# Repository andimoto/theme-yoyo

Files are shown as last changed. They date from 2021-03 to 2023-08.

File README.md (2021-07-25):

# Theme-Yoyo - a Customizable Yoyo

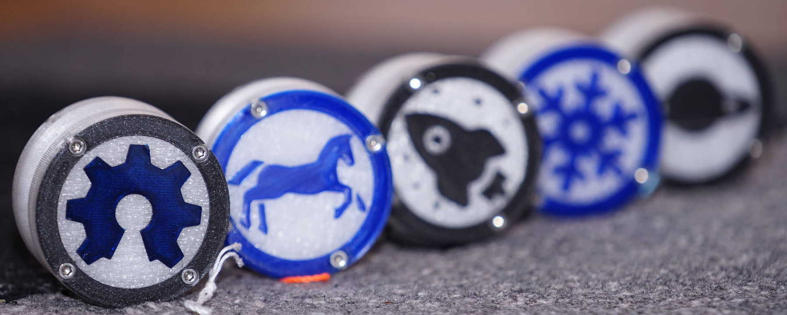
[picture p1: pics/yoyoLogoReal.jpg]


*Place your own graphics on top of the yoyo or customize it!!*

Yoyo is based of two parts, YoyoBase & ThemeBase. The YoyoBase holds both halfs together via screw and bearing (R188KK - 8-Ball-Bearing). The ThemeBase can be customized with multiple vector graphics per ThemeBase.
To add your favorite SVG motive create a 'motive configuration'. This is an array which holds the path to the file and several parameters such as 'moveXYZ', 'extrude' or 'scale'. This 'motive configuration' has to be set to the list 'motiveList'. All motives in this list will be placed on the YoyoBase. This way it is possible to place and combine multiple SVG motives.

Additionally: the 'tools'-directory contains a bash script to convert a png to svg (with pre-conversion to pnm). This script needs __'potrace'__ which can be installed via package manager (on Linux).

SVG graphics with CC0 license can be obtained at:

  - https://publicdomainvectors.org/
  - https://freesvg.org/
  - https://www.svgrepo.com

### Printing
- print ThemeBase on flat surface (graphic up)
- do color change at the graphic to separate it from background
- enable ironing on top layers the get a nice finish
- print resolution 0.1mm
- use PETG for stronger parts

#### Advices
- use filament changes to separate motive from base
- when printing multiple motives, set extrusion length (thickness) to different heights.
  This enables filament changes on different layers and get a multicolor Yoyo!

### Parts
- printed YoYo Parts (2x yoyoBase_xmm.stl, 2x YoyoThemeX.stl)
- one M3x20 screw with M3 nut for Axis
- 8 M3x6 screws (cylinder head screw)
- 2 O-Rings 15x2.5mm
- R188KK Bearing
- Cord (there are ready Yoyo Cords, relatively cheap)

### Assembling
- place the bearing onto the center of the yoyo base
- place the o-ring in both yoyo bases
- put both yoyo bases together (may be necessary to press them carefully together)
  - they should be holded together by the bearing
- screw both yoyo bases together with the M3x20 screw (do not overthight the axis)
- screw the theme parts on top of each base carefully (do not overthight them)
  - tip: measure the weigth of the theme parts and balance them out with small parts of filament
    which you can place into the furrow/gouge which are extra made for weigth balancing
- maybe the yoyo needs to be weared in some minutes

### Images
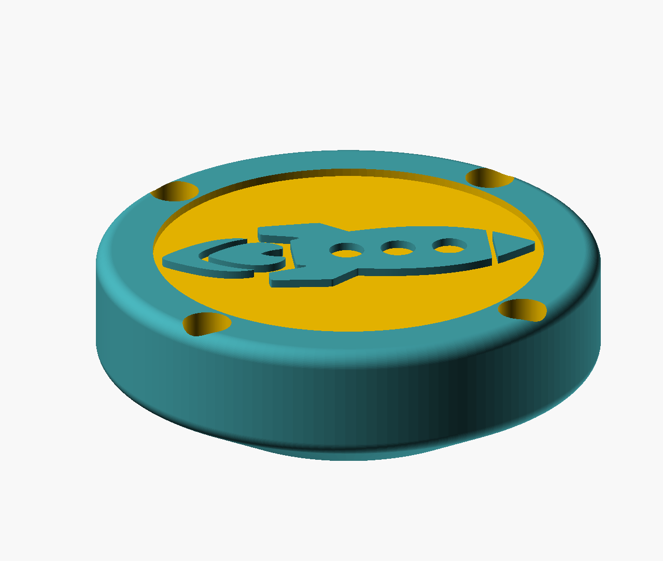
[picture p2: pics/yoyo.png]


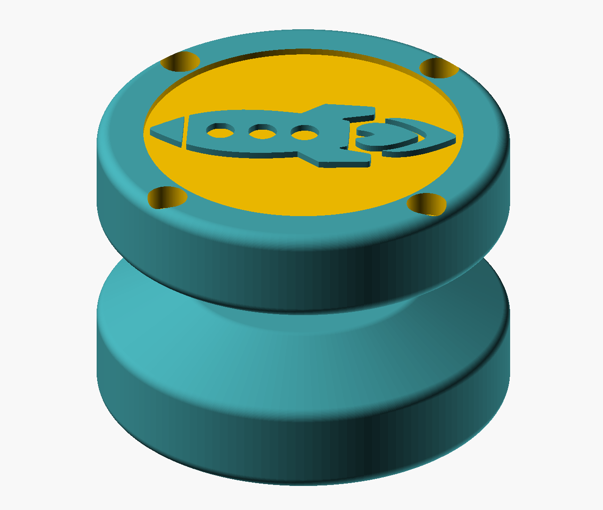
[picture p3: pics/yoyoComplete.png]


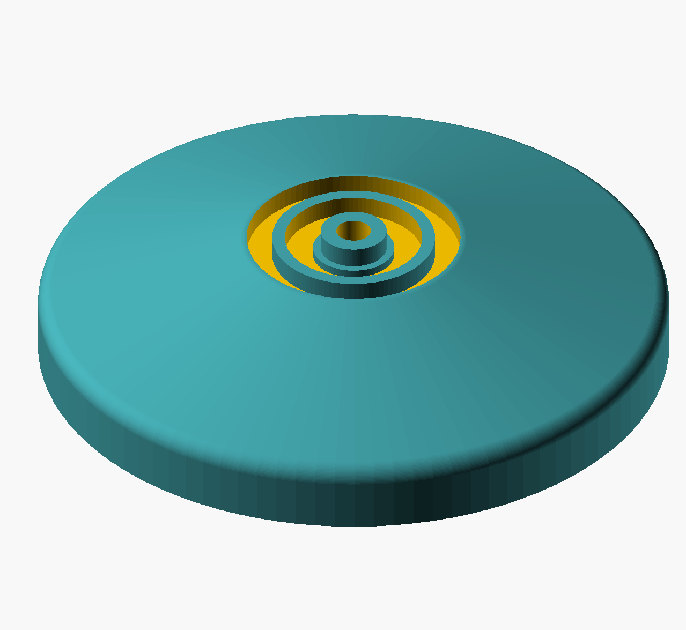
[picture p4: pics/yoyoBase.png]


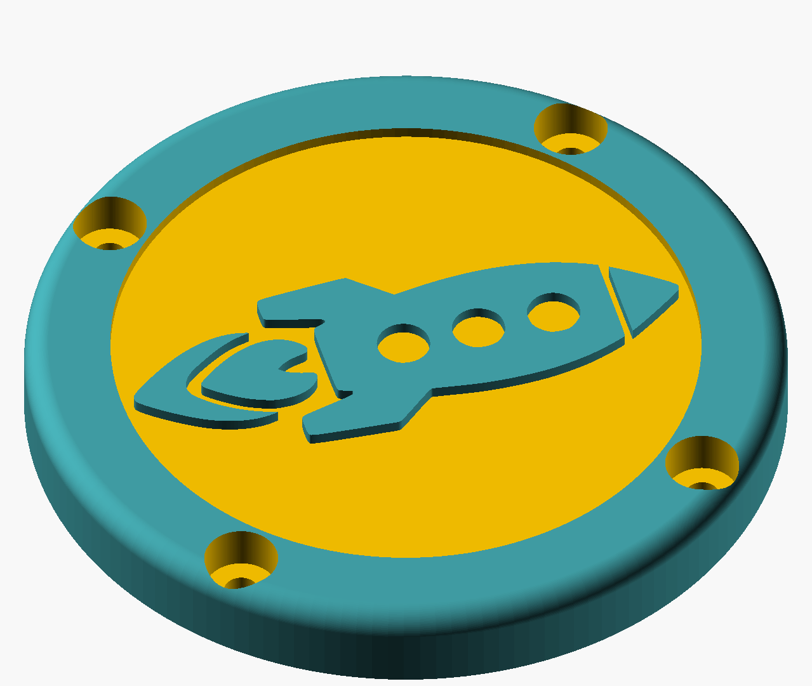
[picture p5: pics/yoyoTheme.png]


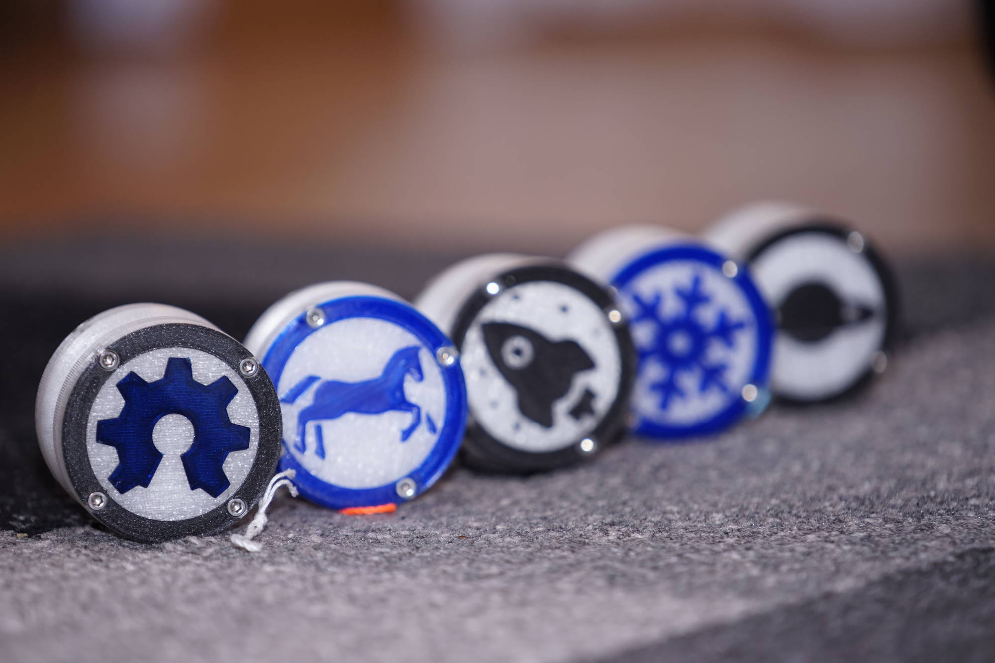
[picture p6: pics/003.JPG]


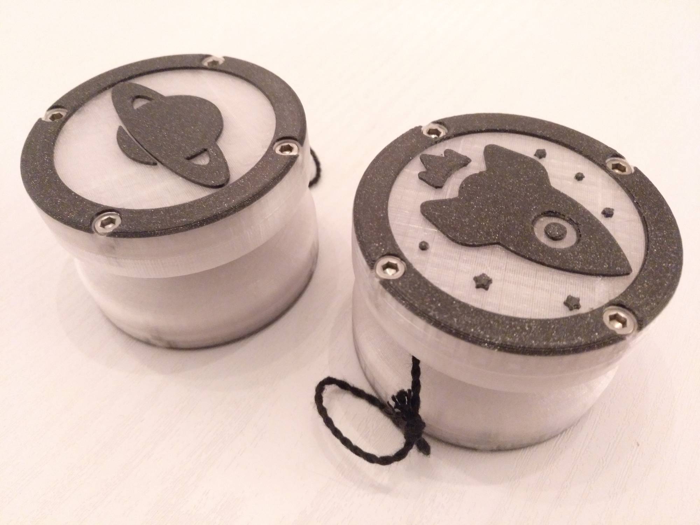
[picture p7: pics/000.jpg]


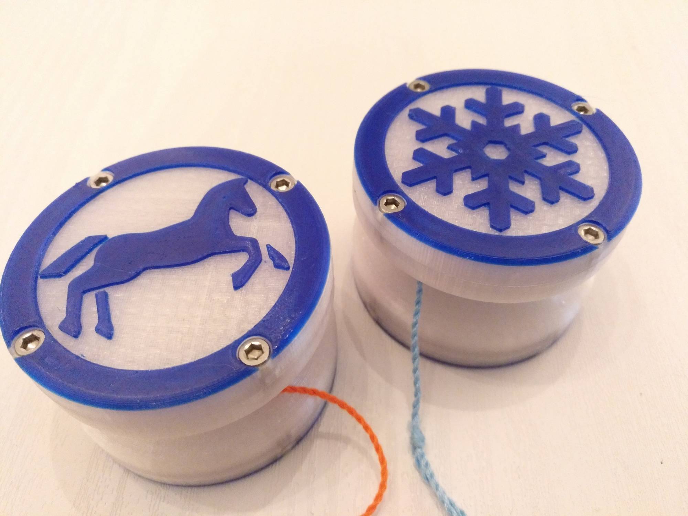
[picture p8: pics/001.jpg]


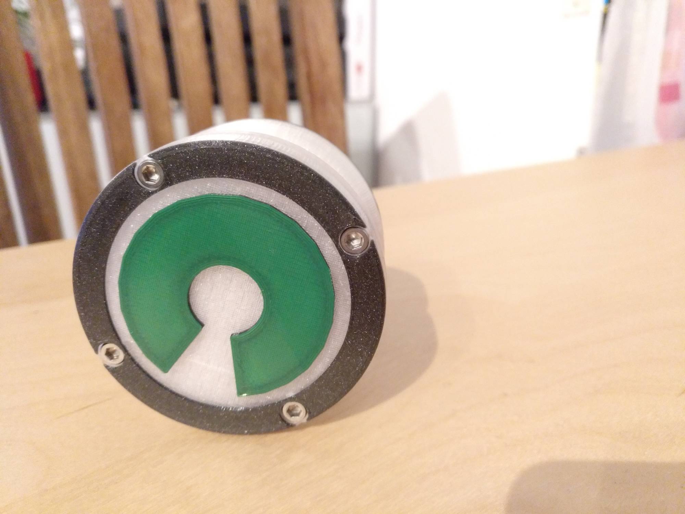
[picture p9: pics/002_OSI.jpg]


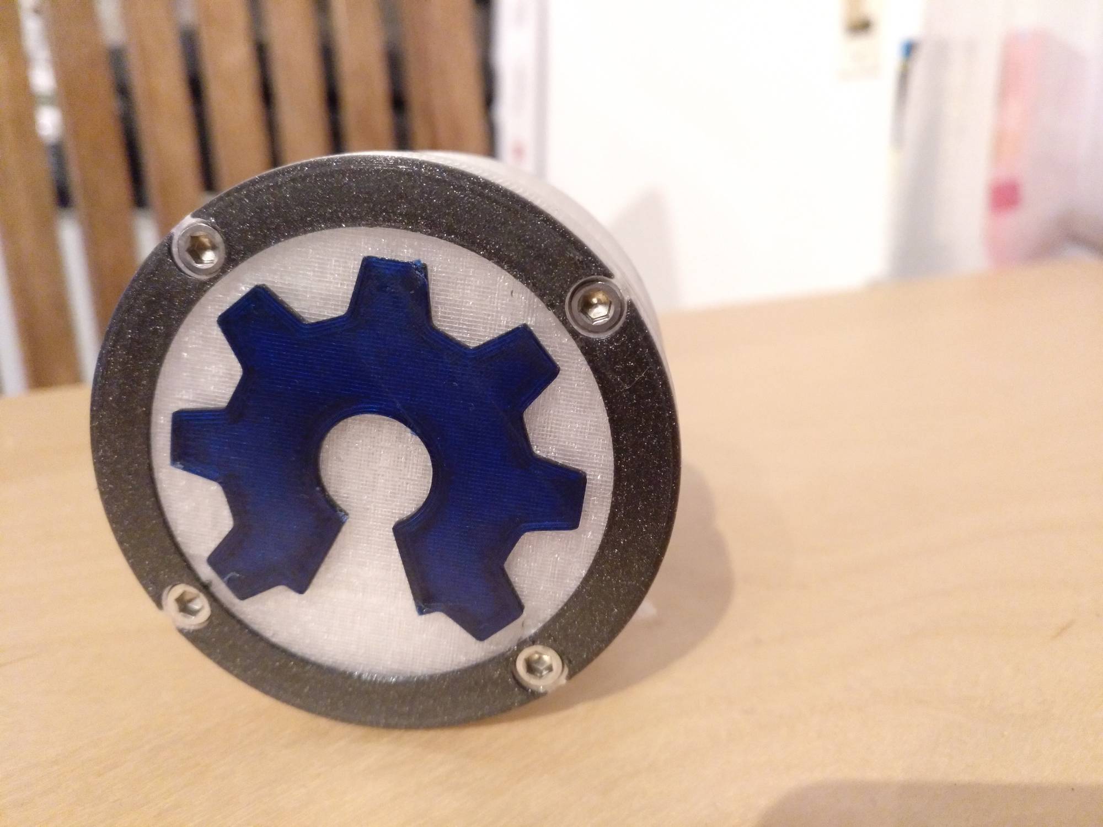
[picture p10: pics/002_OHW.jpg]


# LICENSE

<br />Dieses Werk ist lizenziert unter einer <a rel="license" href="http://creativecommons.org/licenses/by-sa/4.0/">Creative Commons Namensnennung - Weitergabe unter gleichen Bedingungen 4.0 International Lizenz</a>.

<br />This work is licensed under a <a rel="license" href="http://creativecommons.org/licenses/by-sa/4.0/">Creative Commons Attribution-ShareAlike 4.0 International License</a>.

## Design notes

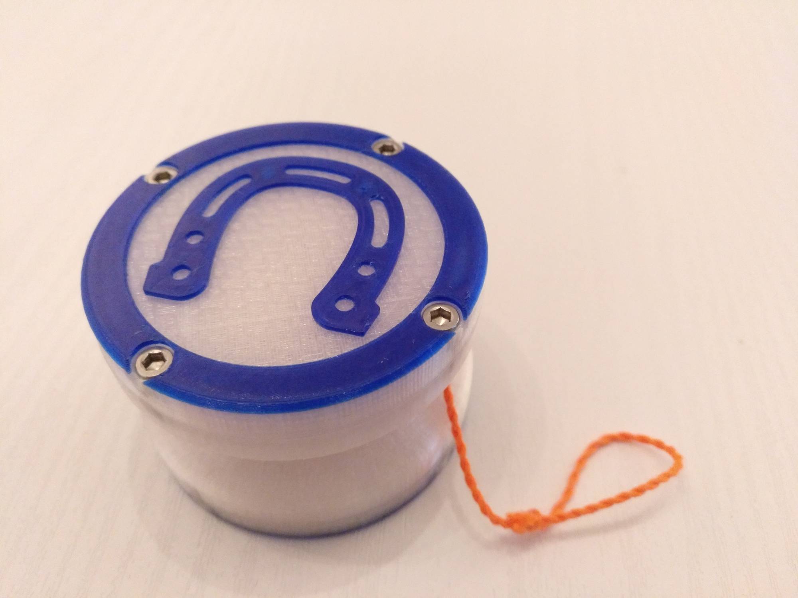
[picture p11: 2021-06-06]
pics/002_horseshoe.jpg

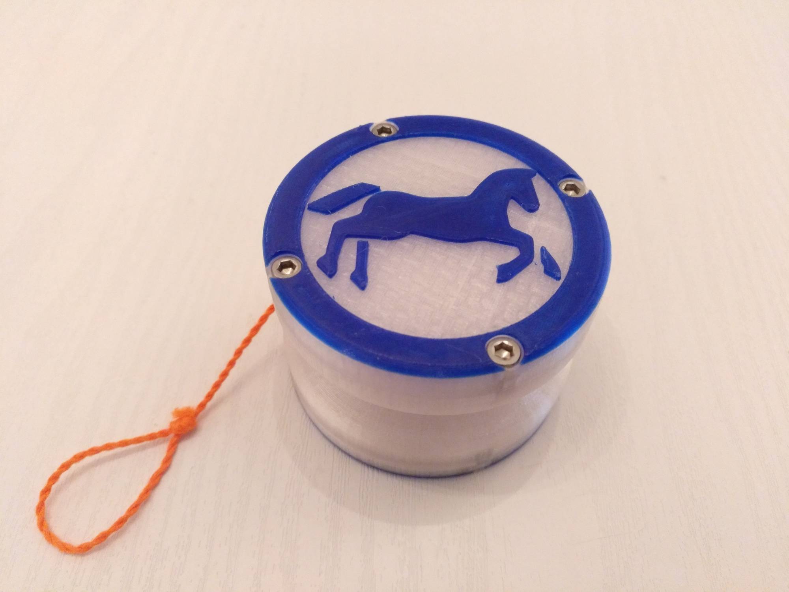
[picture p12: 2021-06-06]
pics/002_horse.jpg

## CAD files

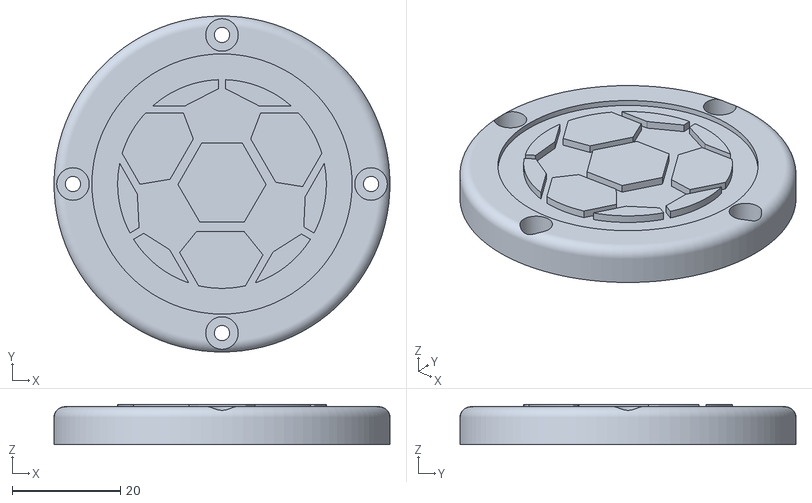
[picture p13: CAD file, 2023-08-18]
stl/yoyoThemeBall.stl
62.0 x 62.0 x 7.40

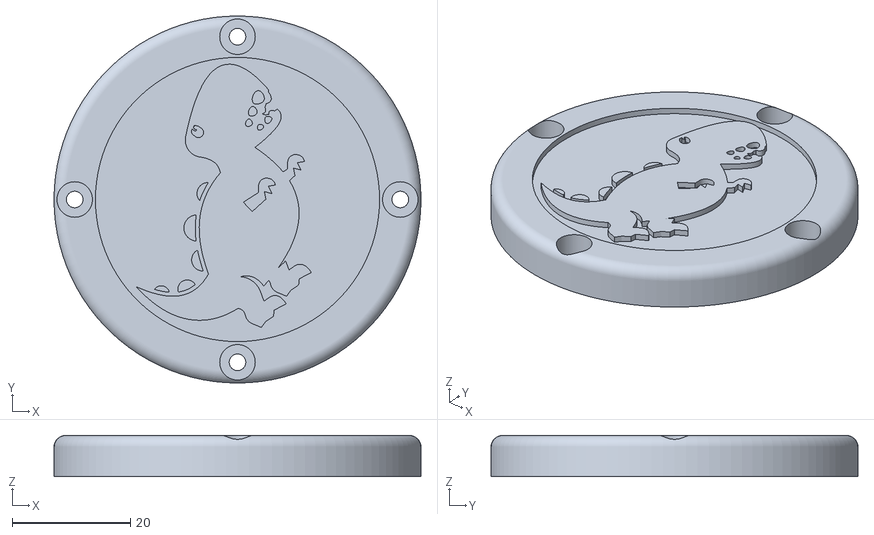
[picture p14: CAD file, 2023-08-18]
stl/yoyoThemeTRex.stl
62.0 x 62.0 x 7.00

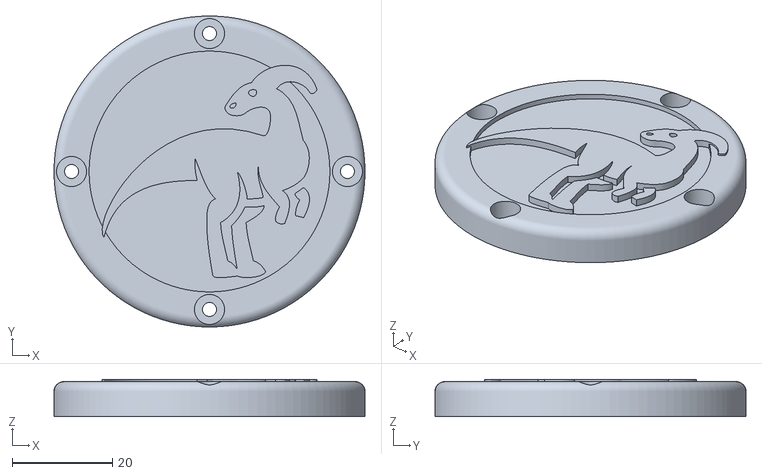
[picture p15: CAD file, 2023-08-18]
stl/yoyoThemeDino001.stl
62.0 x 62.0 x 7.40

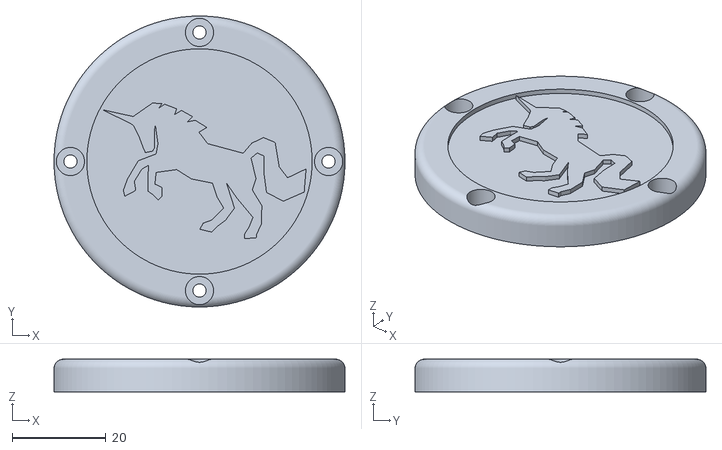
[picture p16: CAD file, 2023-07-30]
stl/yoyoThemeUnicorn001.stl
62.0 x 62.0 x 7.00

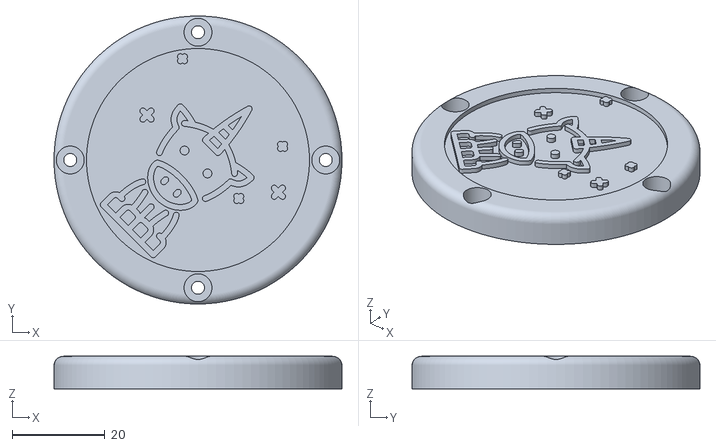
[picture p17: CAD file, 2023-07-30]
stl/yoyoThemeUnicorn005.stl
62.0 x 62.0 x 7.00

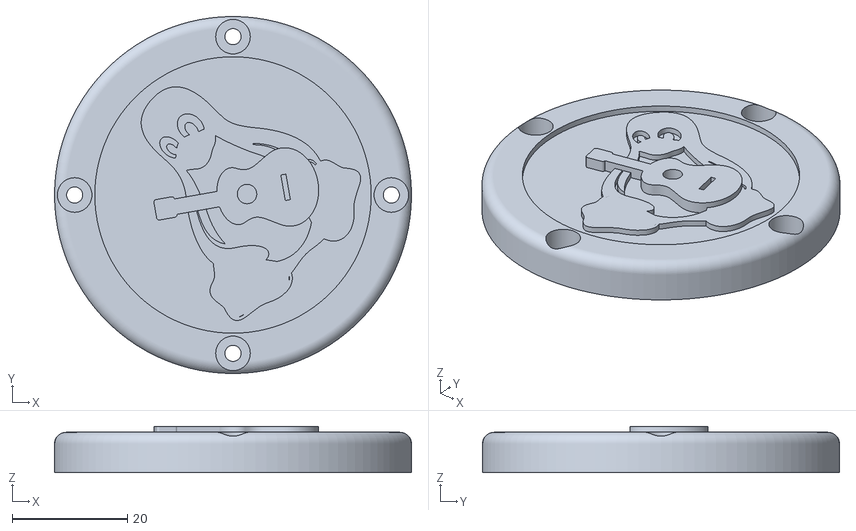
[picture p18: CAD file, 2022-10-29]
stl/yoyoThemeTuxGuitar.stl
62.0 x 62.0 x 8.00

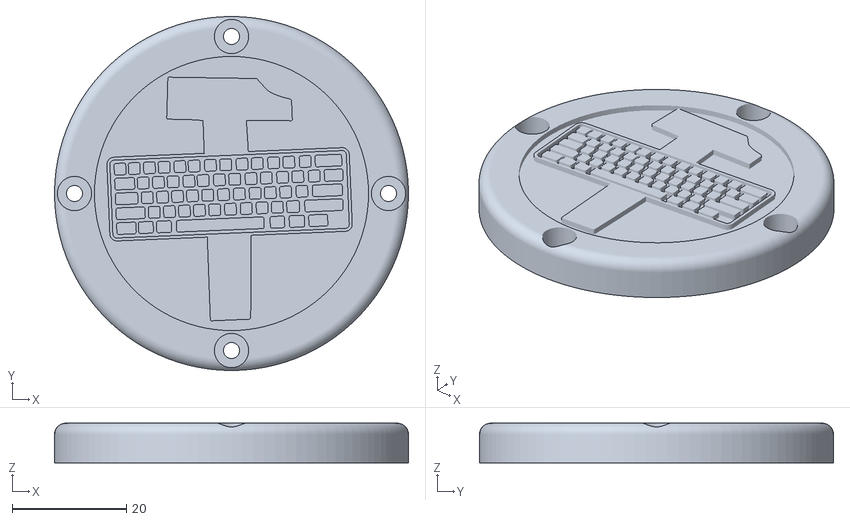
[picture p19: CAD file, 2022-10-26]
stl/yoyoThemeKeyboard2.stl
62.0 x 62.0 x 7.00

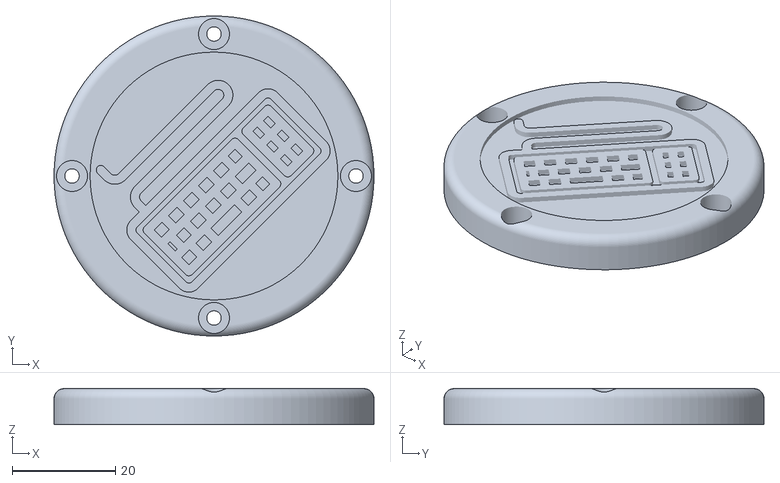
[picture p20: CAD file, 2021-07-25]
stl/yoyoThemeKeyboard.stl
62.0 x 62.0 x 7.00

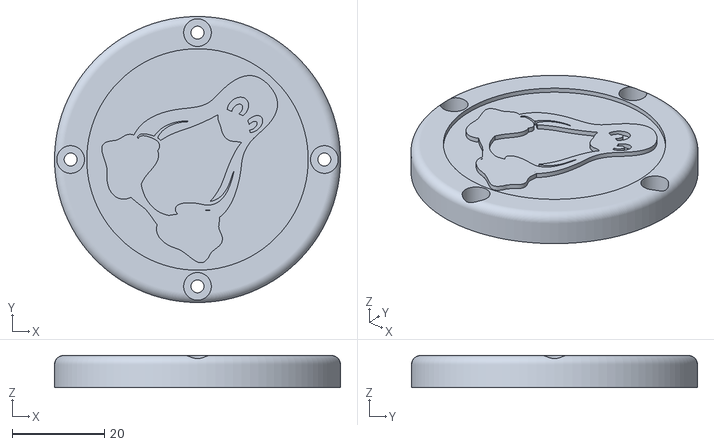
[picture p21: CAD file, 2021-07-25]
stl/yoyoThemeTux.stl
62.0 x 62.0 x 7.00

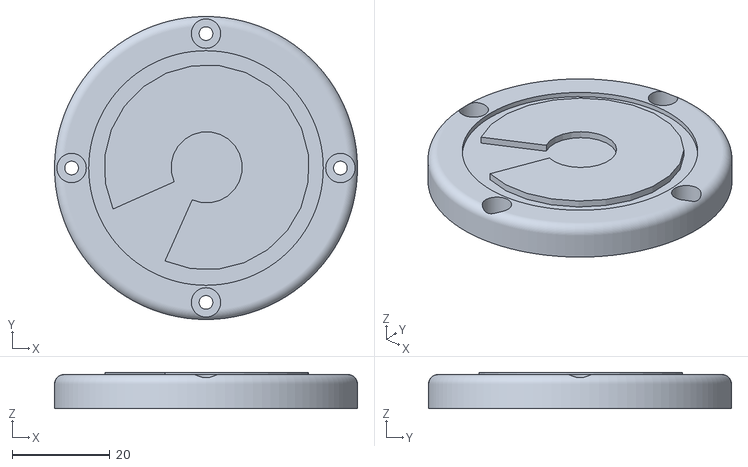
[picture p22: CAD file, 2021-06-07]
stl/yoyoThemeOSInit.stl
62.0 x 62.0 x 7.40

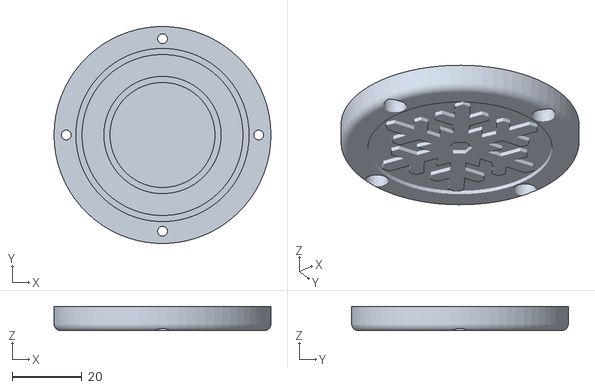
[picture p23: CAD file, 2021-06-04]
stl/yoyoThemeSnowflake.stl
62.0 x 61.9 x 7.00

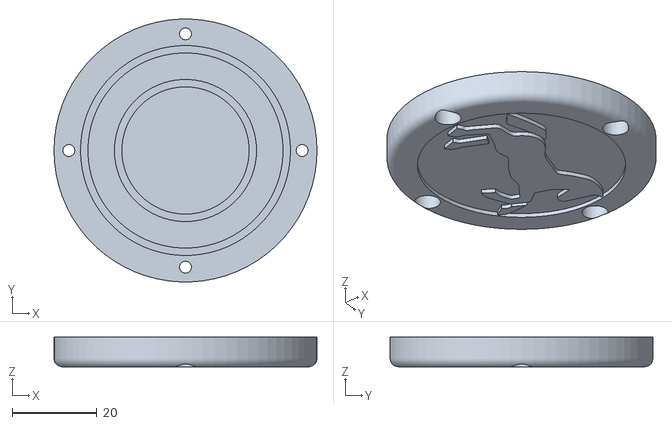
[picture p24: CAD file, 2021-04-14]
stl/yoyoThemeHorse.stl
62.0 x 61.9 x 7.00

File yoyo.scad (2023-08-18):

/* yoyo.scad
Author: andimoto@posteo.de
----------------------------
for placing assambled parts and
single parts set 'showBase' or 'showTop' to 'true'

*/


$fn=100;

/* ################### !!! Show Parts  !!! ############################ */

// true to show Base
showBase = false;
// 0 = no theme, 1 = motive 1 | 2 = motive 2 | 3 = both sides
showThemeBaseNr = 2; // [0,1,2,3]
// true to show base and theme part togehter
showYoyoBuild = false;

/* ################### !!! Configure Motives  !!! ############################ */

/* place svg file configs */
motiveConf1 = [
"svg/dino001.svg",  // file motive
true,           // center SVG
0,              // mirror on x axis
0.25,           // scale SVG
0,              // x Move SVG
0,              // y Move SVG
0,              // z Move SVG
0,             // rotate SVG
1.4               // extrude SVG (thickness)
];

motiveConf2 = [
"svg/unicorn004.svg",  // file motive
true,           // center SVG
1,              // mirror on x axis
0.23,           // scale SVG
2,              // x Move SVG
-2.5,              // y Move SVG
0,              // z Move SVG
15,             // rotate SVG
1               // extrude SVG (thickness)
];

motiveConf3 = [
"svg/trex001.svg",  // file motive
true,           // center SVG
0,              // mirror on x axis
0.14,           // scale SVG
-3,              // x Move SVG
-3,              // y Move SVG
0,              // z Move SVG
45,             // rotate SVG
1.4               // extrude SVG (thickness)
];

/* add each motive configuration to this array */
motiveListA = [
  motiveConf1,
  /* motiveConf2 */
];

motiveListB = [
  motiveConf3,
  /* motiveConf3 */
];


/* #################################################################### */


diameter1=62;
diameter2=25;
baseThickness=20;

baseCutAt=7;


/* roundness of edges : possible values: 0...5*/
edgeRadius=2;

bearingPlatoHeigth=2;
bearingPlatoDiameter=21;
bearingCutoutDepth=2;

bearingPlatoInnerDia=16;
bearingPlatoInnerDia2=13.5;


bearingStem1_Dia=6.5;
bearingStem1_Heigth=2.8;
bearingStem2_Dia=8;
bearingStem2_Heigth=0.8;

screwHoleR=1.7;
screwCylinderR=5;
screwCylinderHeight=6;

screwPlateR=5;

extra=0.1;


plateScrewHeadDia=5.4 +0.6; //screw head diameter + tolerance
plateScrewHeadHeight=2.8 +1; //screw head heigth + tolerance
plateScrewDia=3 -0.2; //screw diameter - tolerance
plateScrewHeight=6 +0.2; //screw heigth + tolerance

balanceRingHeight=2;
balanceRing1r=23;
balanceRing2r=15;


/* ################### !!! MODULES  !!! ############################ */

module balanceRing(rInner=20,rOuter=21.75)
{
  difference() {
    cylinder(r=rOuter,h=balanceRingHeight);
    translate([0,0,-extra/2]) cylinder(r=rInner,h=balanceRingHeight+extra);
  }
}
/* balanceRing(); */



module themeMotive(motiveList)
{

  for(motive = motiveList)
  {
    translate([motive[4],motive[5],motive[6]])
    mirror([motive[2],0,0])
    rotate([0,0,motive[7]])
    scale([1,1,motive[8]])
    linear_extrude(height=1)
    scale(motive[3])
    import(motive[0], center=motive[1]);
  }
}


module bearingCutout()
{
  union()
  {
    difference() {
      cylinder(r=bearingPlatoInnerDia/2, h=bearingPlatoHeigth);
      cylinder(r=bearingPlatoInnerDia2/2, h=bearingPlatoHeigth+extra);
    }
    cylinder(r=bearingStem1_Dia/2, h=bearingStem1_Heigth);
    cylinder(r=bearingStem2_Dia/2, h=bearingStem2_Heigth);
  }
}

/* translate([0,0,30]) bearingCutout(); */

module yoyoBase()
{
  translate([0,0,-baseCutAt])
  difference() {
    /* upper yoyo base */
    union()
    {
      translate([0,0,edgeRadius])
      difference() {
        minkowski() {
          union()
          {
            /* complete yoyo half base for minkowski calculation */
            translate([0,0,baseThickness/2]) cylinder(r1=diameter1/2-edgeRadius,
                      r2=diameter2/2-edgeRadius,
                      h=baseThickness/2-edgeRadius*2);
            translate([0,0,0]) cylinder(r=diameter1/2-edgeRadius,h=baseThickness/2);
          }
          sphere(r=edgeRadius);
        }
        /* remove lower half of this upper base - this enables supportless printing */
        translate([0,0,-edgeRadius-extra]) cylinder(r=diameter1/2+edgeRadius*2,
                                      h=+extra+baseThickness/2-(baseThickness/2-baseCutAt));

        /* bearing cutouts */
        translate([0,0,baseThickness-edgeRadius-bearingCutoutDepth]) cylinder(r=bearingPlatoDiameter/2, h=bearingPlatoHeigth+extra);
      }
      /* place cutout for yoyo bearing */
      translate([0,0,baseThickness-edgeRadius]) bearingCutout();

    }
    /* supportless axes screw hole */
    cylinder(r=screwHoleR,h=baseThickness+bearingStem1_Heigth);
    translate([0,0,baseCutAt-extra]) cylinder(r=screwCylinderR,h=screwCylinderHeight+extra);
    translate([-screwHoleR,-screwCylinderR,screwCylinderHeight+baseCutAt-extra])
      cube([screwHoleR*2,screwCylinderR*2,0.2+extra]);
    translate([-screwHoleR,-screwHoleR,screwCylinderHeight+baseCutAt+0.2-extra])
      cube([screwHoleR*2,screwHoleR*2,0.2+extra]);

    /* screws to fix upper yoyo base to lower yoyo base */
    translate([(diameter1/2)-edgeRadius/2-screwPlateR/2,0,baseCutAt-extra])
      cylinder(r=plateScrewDia/2, h=screwCylinderHeight);
    translate([-(diameter1/2)+edgeRadius/2+screwPlateR/2,0,baseCutAt-extra])
      cylinder(r=plateScrewDia/2, h=screwCylinderHeight);
    translate([0,(diameter1/2)-edgeRadius/2-screwPlateR/2,baseCutAt-extra])
      cylinder(r=plateScrewDia/2, h=screwCylinderHeight);
    translate([0,-(diameter1/2)+edgeRadius/2+screwPlateR/2,baseCutAt-extra])
      cylinder(r=plateScrewDia/2, h=screwCylinderHeight);


    /* Debugging: Middle Cut through base */
    /* translate([-diameter1/2,0,0]) cube([diameter1,diameter1/2,baseThickness+2]); */
  }
}


module screwHole()
{
  translate([0,0,baseThickness/2+edgeRadius*2-plateScrewHeadHeight])
    cylinder(r=plateScrewHeadDia/2, h=plateScrewHeadHeight+extra);
  cylinder(r=plateScrewDia/2, h=baseThickness/2+edgeRadius*2);
}

module yoyoThemeBase(motiveNr = 0)
{
  difference() {
    translate([0,0,-baseCutAt])
    minkowski()
    {
      translate([0,0,edgeRadius]) cylinder(r=diameter1/2-edgeRadius,h=baseThickness/2);
      sphere(r=edgeRadius);
    }

    translate([0,0,-baseCutAt])
    union()
    {
      translate([0,0,(baseThickness/2+edgeRadius*2)-0.5])
        cylinder(r=(diameter1/2-edgeRadius-screwPlateR), h=1+extra, center=true);

      /* screws to fix upper yoyo base to lower yoyo base */
      translate([(diameter1/2)-edgeRadius/2-screwPlateR/2,0,0]) screwHole();
      translate([-(diameter1/2)+edgeRadius/2+screwPlateR/2,0,0]) screwHole();
      translate([0,(diameter1/2)-edgeRadius/2-screwPlateR/2,0]) screwHole();
      translate([0,-(diameter1/2)+edgeRadius/2+screwPlateR/2,0]) screwHole();
    }

    translate([0,0,-extra])
    balanceRing(rInner=balanceRing1r, rOuter=balanceRing1r+1.75+extra);

    translate([0,0,-extra])
    balanceRing(rInner=balanceRing2r, rOuter=balanceRing2r+1.75+extra);

    translate([0,0,-(baseThickness/2+edgeRadius*2)])
      cylinder(r=diameter1/2+edgeRadius*2,h=baseThickness/2+edgeRadius*2);

    /* Debugging: Middle Cut through base */
    /* translate([-diameter1/2,0,0]) cube([diameter1,diameter1/2,baseThickness+2]); */
  }

  translate([0,0,(baseThickness/2+edgeRadius*2)-baseCutAt-1])
  union()
  {
    if(motiveNr == 1)
    {
      themeMotive(motiveListA);
    }

    if(motiveNr == 2)
    {
      themeMotive(motiveListB);
    }
  }
  /* themeMotive(fileMotive2); */
}


if(showBase)
{
  translate([0,0,0])
  yoyoBase();
}

if(showThemeBaseNr)
{
  if(showThemeBaseNr == 3)
  {
    yoyoThemeBase(1);
    translate([diameter1+10,0,0]) yoyoThemeBase(2);
  }else{
    /* rotate([0,180,0])  */
    yoyoThemeBase(showThemeBaseNr);
  }
}

if(showYoyoBuild)
{
  rotate([0,90,0])
  union()
  {
    translate([0,0,0]) yoyoBase();
    rotate([0,180,0]) yoyoThemeBase(motiveNr = 1);
  }
}

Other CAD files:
stl/yoyoThemeDino002.stl
stl/yoyoThemeTRex2.stl
stl/yoyoThemePixelDino.stl
stl/yoyoThemeGuitar.stl
stl/yoyoThemeOSHW.stl
stl/yoyoThemeHorseShoe.stl
stl/yoyoBase_3mmScrew.stl
stl/yoyoThemeRocket.stl
stl/yoyoThemeSaturn.stl

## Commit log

2021-03-21 yoyo.stl und yoyo.scad aktualisiert
    [yoyo.scad, yoyo.stl]
2021-03-24 yoyo.scad aktualisiert
    [yoyo.scad]
2021-03-25 Update yoyo.stl and yoyo.scad
    [yoyo.scad, yoyo.stl]
2021-03-26 yoyoThemeBase.stl und yoyo.scad aktualisiert
    [yoyo.scad, yoyoThemeBase.stl]
2021-03-28 yoyo.stl, yoyoBase.stl und 2 weitere dateien aktualisiert...
    [yoyo.scad, yoyo.stl, yoyoBase.stl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]
2021-03-28 README.md, yoyo.png und 5 weitere dateien aktualisiert...
    [yoyo.scad]
2021-03-28 README.md, Rocket-Black.svg und 2 weitere dateien aktualisiert...
    [yoyo.scad]
2021-03-28 yoyoBase.stl, yoyoThemeBaseRocket.stl und yoyoThemeBaseSaturn.stl aktualisiert
    [yoyoBase.stl, yoyoThemeBaseRocket.stl, yoyoThemeBaseSaturn.stl]
2021-03-29 Update yoyoThemeBaseRocket.stl, Rocket001.svg, and yoyo.scad
    [yoyo.scad, yoyoThemeBaseRocket.stl]
2021-03-31 yoyoBase.stl, yoyoThemeBase.stl und 5 weitere dateien aktualisiert...
    [yoyo.scad, yoyoBase.stl, yoyoThemeBase.stl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]
2021-04-02 Update yoyoBase.stl and yoyo.scad
    [yoyo.scad, yoyoBase.stl]
2021-04-14 yoyoThemeHorse.stl, yoyoThemeHorseFine.stl und 4 weitere dateien aktualisiert...
    [yoyo.scad, yoyoThemeHorse.stl, yoyoThemeHorseFine.stl]
2021-06-04 README.md, yoyoBase.stl und 8 weitere dateien aktualisiert...
    [yoyo.scad, yoyoBase_3mmScrew.stl, yoyoBase_4mmScrew.stl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]
2021-06-06 README.md, yoyoLogo.png und 8 weitere dateien aktualisiert...
    [yoyo.scad, yoyoBase_3mmScrew.stl, yoyoBase_4mmScrew.stl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]
2021-06-06 README.md, 000.jpg und 6 weitere dateien aktualisiert...
    [yoyo.scad, yoyoBase_3mmScrew.stl]
2021-06-07 Update yoyoThemeOSHW.stl, yoyoThemeOSInit.stl, and yoyo.scad
    [yoyo.scad, yoyoThemeOSHW.stl, yoyoThemeOSInit.stl]
2021-06-07 README.md, 002_OHW.jpg und 7 weitere dateien aktualisiert...
2021-07-25 README.md, yoyoThemeKeyboard.stl und 9 weitere dateien aktualisiert...
    [yoyo.scad, yoyoThemeKeyboard.stl, yoyoThemeTux.stl]
2022-10-26 yoyoThemeKeyboard2.stl, keyboard.svg und 5 weitere dateien aktualisiert...
    [yoyo.scad, yoyoThemeKeyboard2.stl]
2022-10-27 Update yoyoThemeSwitch.stl and switch.svg
2022-10-29 yoyoThemeGuitar.stl und yoyo.scad aktualisiert
    [yoyo.scad, yoyoThemeGuitar.stl]
2022-10-29 yoyoBase_3mmScrew.stl, yoyoThemeTuxGuitar.stl und yoyo.scad aktualisiert
    [yoyo.scad, yoyoBase_3mmScrew.stl, yoyoThemeTuxGuitar.stl]
2023-07-30 yoyoThemeUnicorn001.stl, yoyoThemeUnicorn005.stl und 7 weitere dateien aktualisiert...
    [yoyo.scad, yoyoThemeUnicorn001.stl, yoyoThemeUnicorn005.stl]
2023-08-18 yoyoThemeBall.stl, yoyoThemeDino001.stl und 30 weitere dateien aktualisiert...
    [yoyo.scad, yoyoThemeBall.stl, yoyoThemeDino001.stl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]
